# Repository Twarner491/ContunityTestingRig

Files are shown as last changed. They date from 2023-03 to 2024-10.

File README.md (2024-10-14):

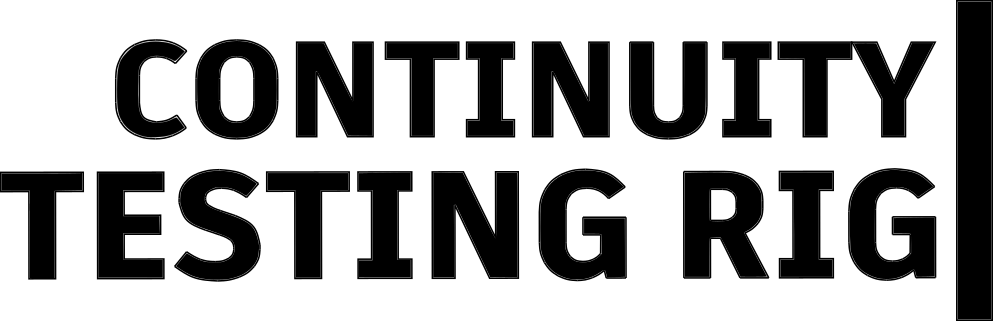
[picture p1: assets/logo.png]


### Devoloped by [Drew Griggs](http://fabacademy.org/2021/labs/charlotte/students/drew-griggs/about/) and [Teddy Warner](https://teddywarner.org/About-Me/about/).

## Documentation -

Our project idea, as discussed with RhythmLink, is a continuity testing rig. This project will be capable of testing and displaying the results of the pinout connections between two ends of a cable with different headers. Our goal is to create a continuity testing rig capable of testing and displaying the connections between the ends of two different cable headers. We will display the results to a webpage using the Raspberry Pico W microcontroller.

The concept behind this project is simple, but our method of display, as well as some methods to reduce the GPIO pins required for the microcontroller will be quite complex, so we worry that we might run into some issues here. The most challenging part of this project will likely be getting the web server to run correctly, as we will be using a RPI Pico W to host the server, but there are very few examples of a project such as this compared to something like an Arduino. A successful project would be able to test the continuity in real time and refresh the users web browser through a visually appealing display.

We used a few sources as guides to setting up a RPI web server, mainly Tom’s Hardware and the Raspberry Pi website - see the *sources* section below.

Our project is significantly more complex than these simple web servers, however, as we will refresh the page automatically, include some javascript and more complex HTML elements to improve the aesthetic, not to mention the continuity testing aspects.

Through the development of the project, we learned a great deal about the principles of static site design, multimedia design with 3D printing, and the integration of software and hardware components. As we developed the initial design stages of the project, we reminded ourselves of the horrors of debugging, going through countless coexisting issues that were causing the failure of our project. As we built up our initial prototype, we discovered, and ultimately resolved, issues involving our diode array, web server generation, board design, and many more. Similarly to our Fab Academy projects, we had many parts working in conjunction with each other. As we traversed the design and manufacturing process, we once again were reminded of the difficulty of getting each component of the project successfully integrated. At times, we would wonder from which component of the project our errors arose from.

Some of the major issues we encountered were due to errors in the board design. Due to an oversight in the main board, we did not include diodes for the final point of connection between each diode chain and output pin, which caused issues with reading pins that should not be high. Furthermore, we had an issue with our self test function. We initially decided to implement transistors to toggle and check each output and input pin, but due to voltage jumping between Gate and Drain despite no Source voltage, this part was unsuccessful. As such, we will not be making any further changes to the prototype, other than implementing a basic self test function with a predetermined cable.

### Electronic Design

The testing rig will likely consist of two separate boards, one main logic and interpretation board and one header board. The logic board will include a RPi Pico W to host the server and interpret data, a power regulation module, a diode array to reduce specific pins into their binary values (to conserve GPIO pins), and a large 2x20 pin header. The header board will include the connectors for each end of the cable and the 2x20 pin connector, as well as a possible self test function to ensure the functionality of the rig. The self test will include a jump between specific pins on each module, and an LED that will flash green assuming the test passes.

We used a few methods to allow the project to be operable on the Raspberry Pico. We designed and implemented an array of diodes to convert any individual input into a binary representation of its pin value, allowing us to test and read 15 possible different wires through 4 input pins. For the header connector board, we designed custom eagle footprints and libraries for the two types of connectors, as well as adding self-test circuits that will connect pins through the switch of a transistor.

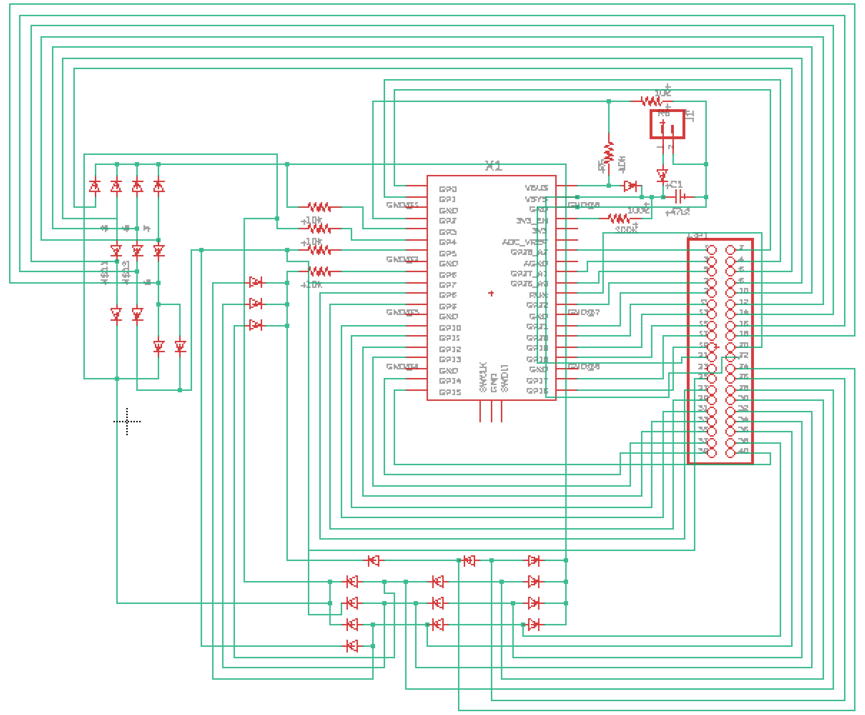
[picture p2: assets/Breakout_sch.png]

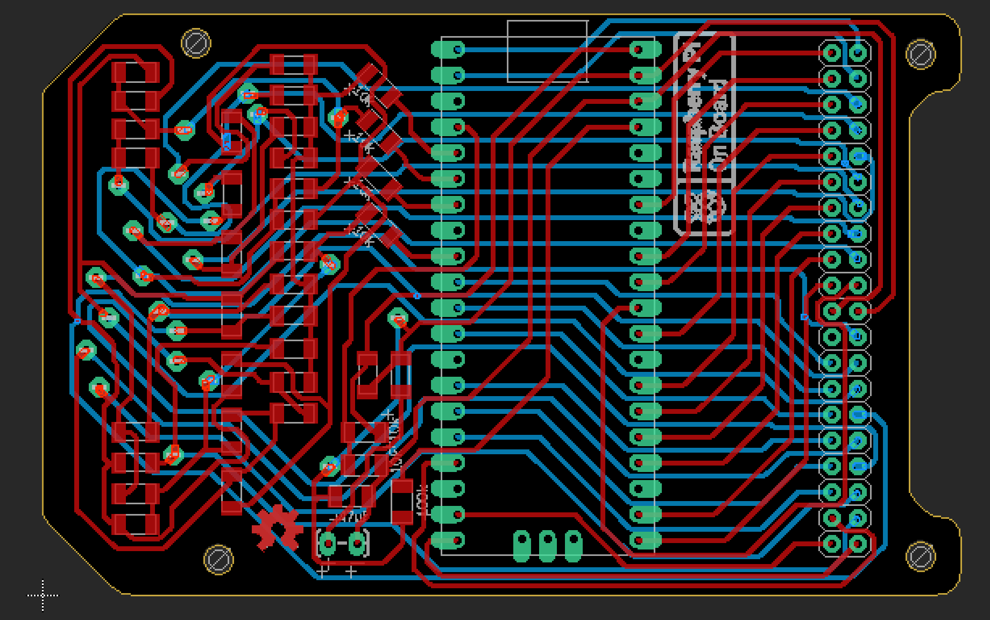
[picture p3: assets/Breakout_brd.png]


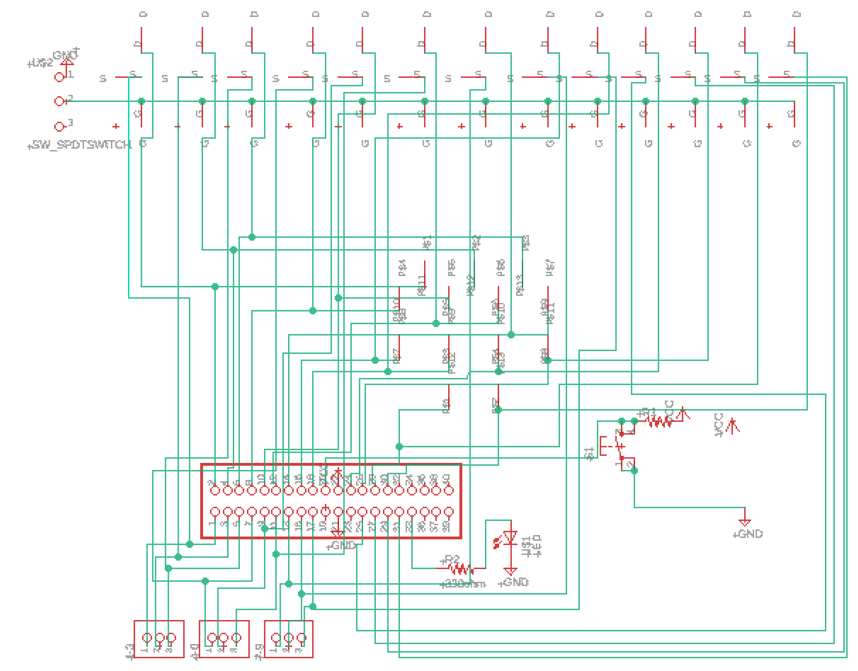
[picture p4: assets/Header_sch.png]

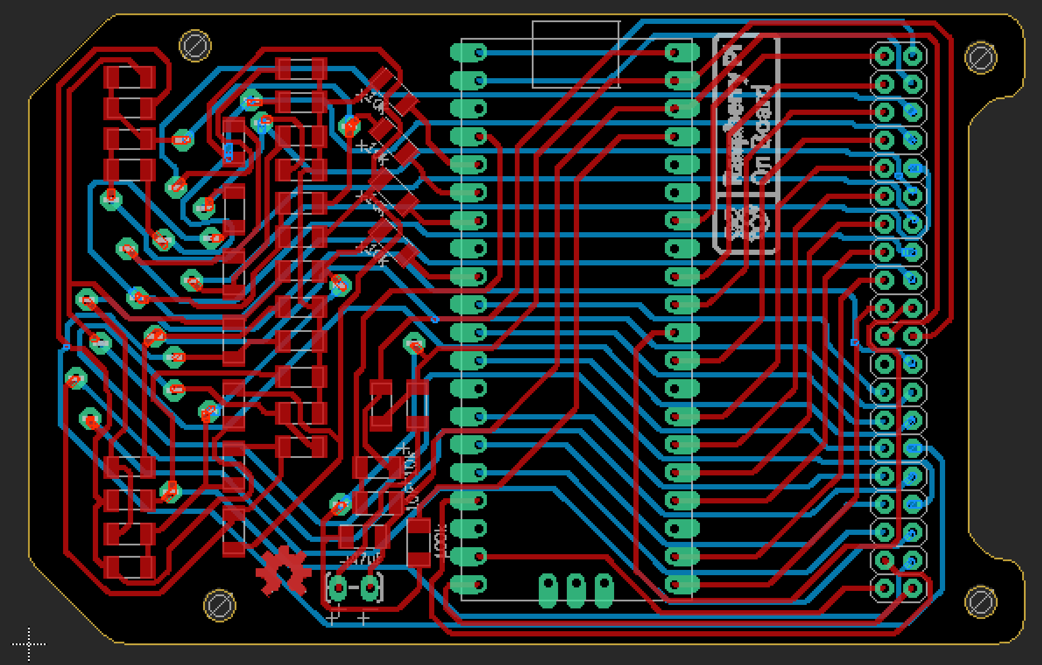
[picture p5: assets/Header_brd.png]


Our project went somewhat to plan. Due to some issues in the testing of our board due to the precision of our lab’s PCB mills as well as the complexity of our board, we had some issues testing the main board. We eventually fixed a bug in the diode array, and the main board was working. The header board took less time, as it was less complex, but due to some issues with voltages jumping across transistors despite no source voltage, we were unable to include our initially planned self test function. After discussions with Rhythmlink, however, we determined that this would not be an issue, and since the board worked without the transistors soldered, we continued with testing. Web and software design and testing took the majority of our allocated time, as this was the first project of this type for both of us, so it took some getting used to programming a web server through micropython.

We mostly used tools oriented to PCB design in our project. We spent the majority of our machine use on the Bantam PCB mills, with some 3D printing of our enclosure towards the end of our project. Our files were EagleCad .sch and .brd schematic and boards, python files, fusion project files, and html files.

### Software

The operation of the Pico makes designing and editing a webpage in real time very annoying. It requires a string object to be sent through a library in the Pico, so we had to code a way to implement the updates of the test through splicing strings together. Apart from some hiccups in the testing of this component, however, the code was fairly simple. It loops through each of nine output pins, and reads the corresponding binary value of the input pins that corresponds to the pin number in the header cable.

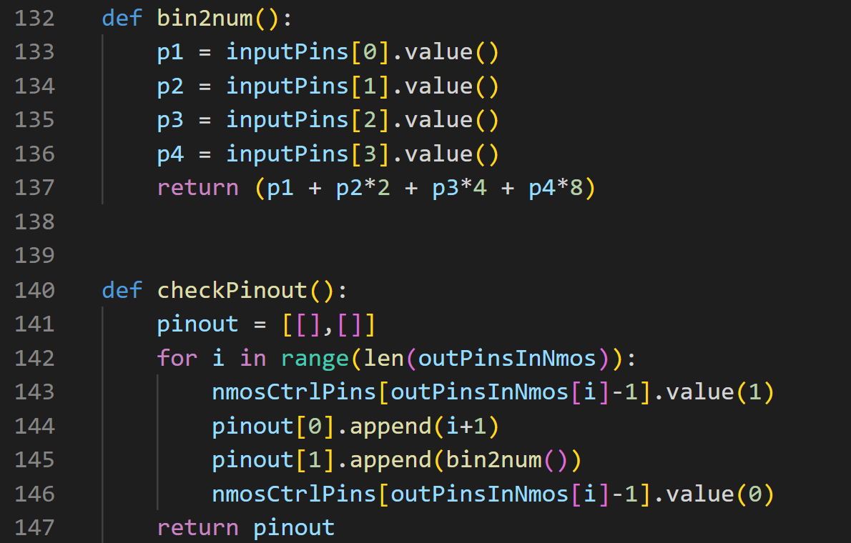
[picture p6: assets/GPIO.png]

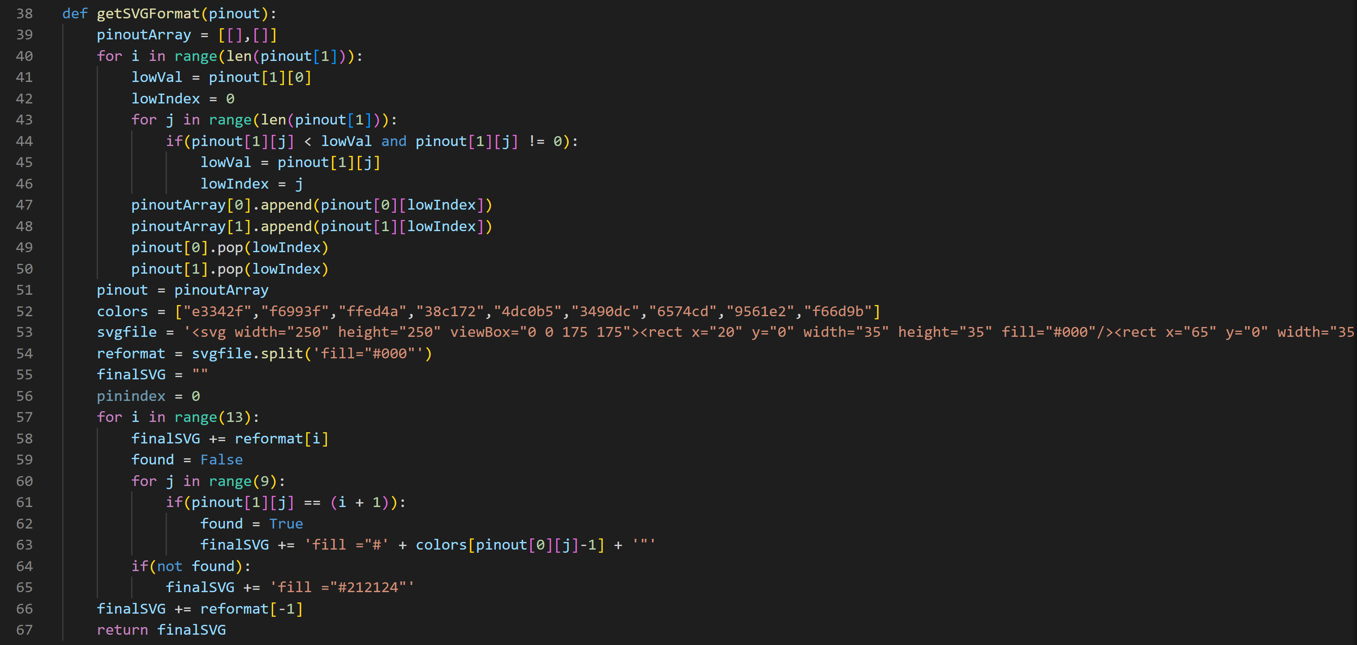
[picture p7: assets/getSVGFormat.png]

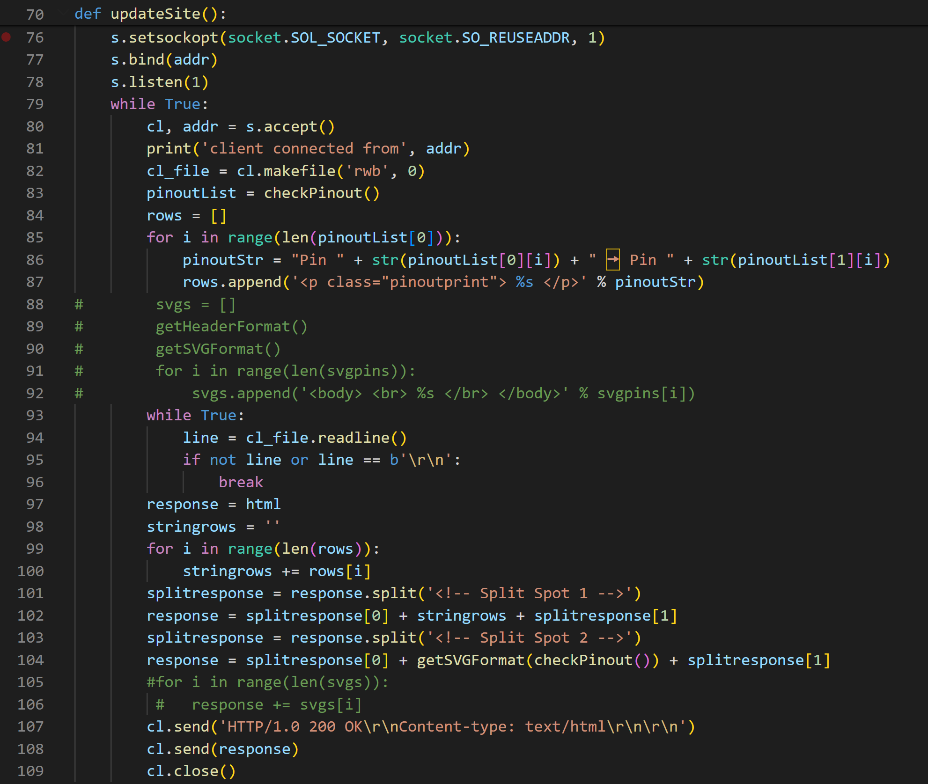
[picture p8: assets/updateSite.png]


### CAD

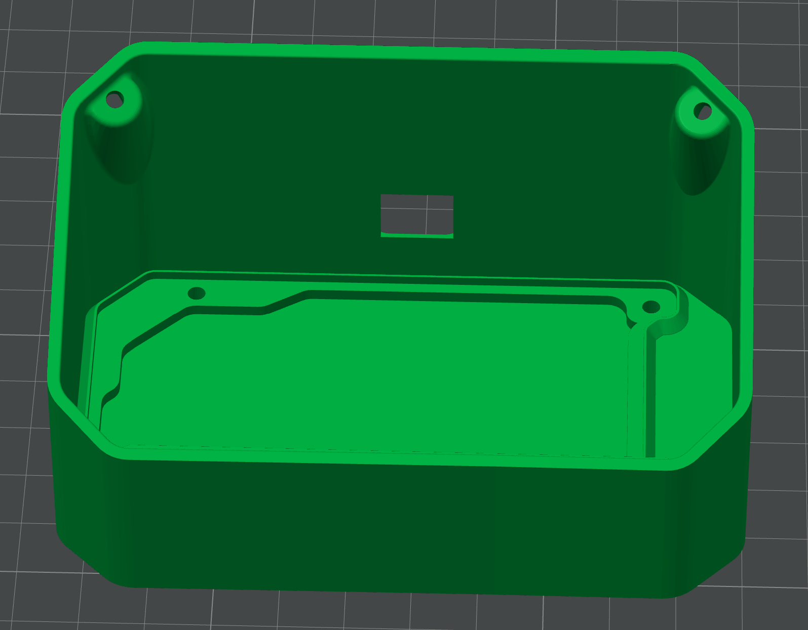
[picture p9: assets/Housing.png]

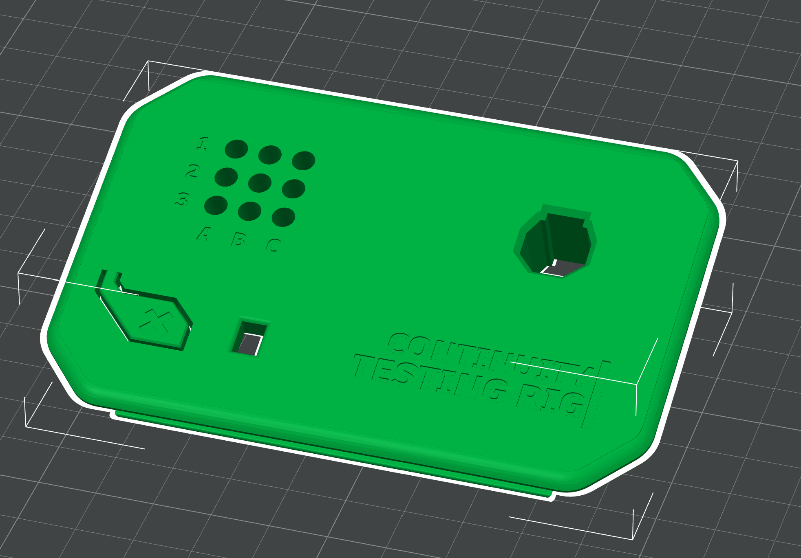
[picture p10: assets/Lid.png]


### Testing

https://github.com/user-attachments/assets/56f717f2-6f56-4a5b-b8bf-3c429beb7c11

https://github.com/user-attachments/assets/bd0a2b19-7a08-46a7-8804-3f2991451b49

### Assembly Instructions

- Download necessary files from github (link above)
- 3D print outer case
- Order or manufacture main and header board
- Solder components to each board
- Download Thonny and the python script
- Use dupont connectors and solid wires to create header cable adapters
- Add your wifi information to the ssid and password in the python file
- Boot the pico w with the boot file. Instructions can be found on raspberry pico article
- Run the script

## Sources -
 - [https://www.tomshardware.com/how-to/raspberry-pi-pico-setup](https://www.tomshardware.com/how-to/raspberry-pi-pico-setup)
 - [https://datasheets.raspberrypi.com/picow/pico-w-datasheet.pdf](https://datasheets.raspberrypi.com/picow/pico-w-datasheet.pdf)

---
- [Fork this repository](https://github.com/Twarner491/ContunityTestingRig/fork)
- [Watch this repo](https://github.com/Twarner491/ContunityTestingRig/subscription)
- [Create issue](https://github.com/Twarner491/ContunityTestingRig/issues/new)

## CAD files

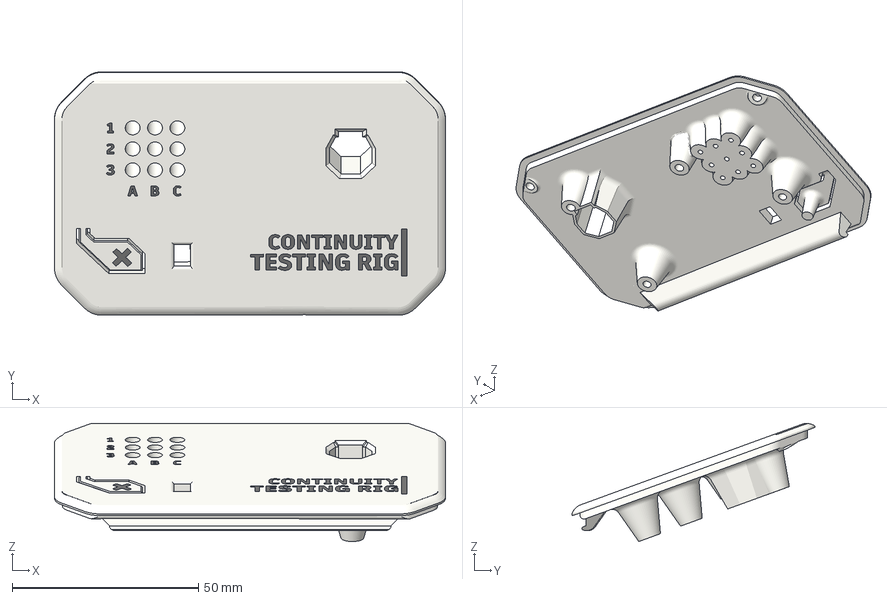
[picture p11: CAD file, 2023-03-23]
CAD/3DPrintedLid.3mf
104.9 x 65.3 x 31.7 mm

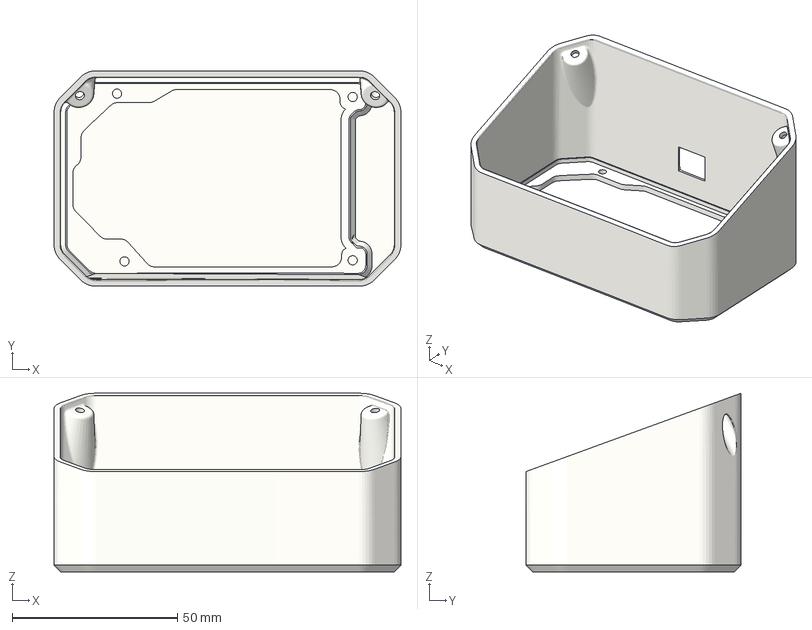
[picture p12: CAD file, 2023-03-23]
CAD/3dPrintedHousing.3mf
104.9 x 65.2 x 54.0 mm

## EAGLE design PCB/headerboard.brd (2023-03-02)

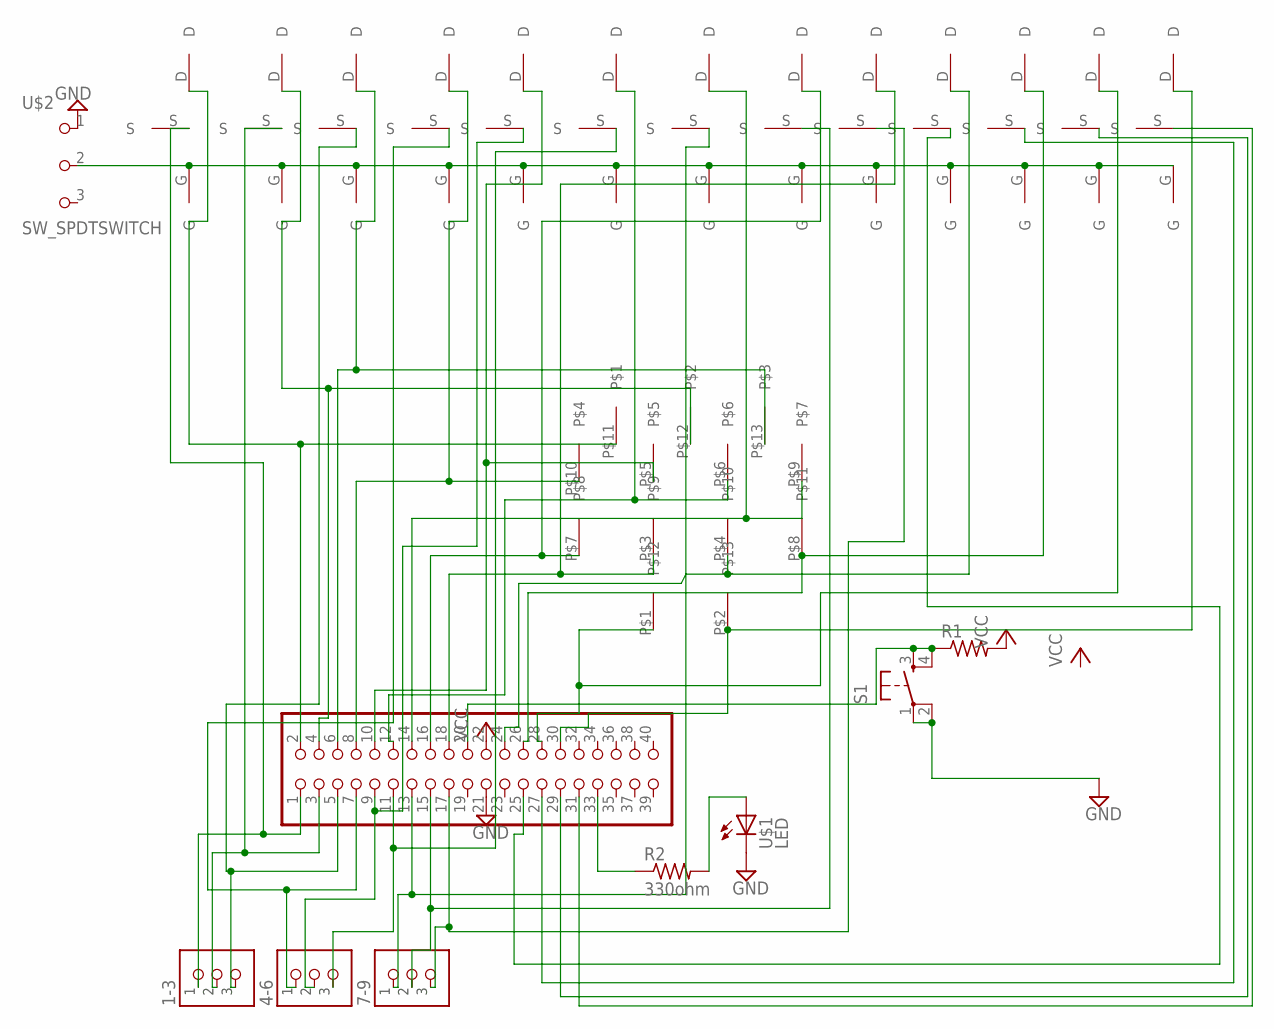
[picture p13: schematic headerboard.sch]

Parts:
1-3, 4-6, 7-9: CONN_03_TERM'-FABLAB'; ED555DS-3DS
JP1: PINHD-2X20; 2X20
R1: R1206FAB
R2: 330ohm; R1206FAB
S1: SW_SWITCH_TACTILE_6MM6MM_SWITCH; 6MM_SWITCH
U$1: LED; LED1206
U$2: SW_SPDTSWITCH; SPDTSWITCH
U$3, U$4, U$5, U$6, U$7, U$8, U$9, U$10, U$11, U$12, U$13, U$14, U$15: SOT23NMOS
U$19: 13PINHEADER; 13HEADER

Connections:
GND: JP1.21, S1.1, S1.2 (P1), U$1.2 (C), U$2.1
unnamed: U$2.2, U$3.G, U$4.G, U$5.G, U$6.G, U$7.G, U$8.G, U$9.G, U$10.G, U$11.G, U$12.G, U$13.G, U$14.G, U$15.G
unnamed: JP1.2, U$3.D, U$19.P$11
unnamed: JP1.4, U$4.D, U$19.P$12
unnamed: JP1.6, U$5.D, U$19.P$13
unnamed: JP1.8, U$6.D, U$19.P$10
unnamed: JP1.12, U$8.D, U$19.P$6
unnamed: JP1.26, U$13.D, U$19.P$8
unnamed: JP1.14, U$9.D, U$19.P$9
unnamed: JP1.16, U$10.D, U$19.P$7
unnamed: JP1.18, U$11.D, U$19.P$3
unnamed: 1-3.2, JP1.3, U$4.S
unnamed: JP1.28, U$14.D, U$19.P$1
unnamed: JP1.24, U$12.D, U$19.P$4
unnamed: JP1.30, U$15.D, U$19.P$2
unnamed: 1-3.3, JP1.5, U$5.S
unnamed: JP1.20, R1.1, S1.3 (S), S1.4 (S1)
unnamed: 4-6.1, JP1.7, U$6.S
unnamed: 4-6.2, JP1.9, U$7.S
unnamed: 4-6.3, JP1.11, U$8.S
unnamed: 7-9.1, JP1.13, U$9.S
unnamed: JP1.10, U$7.D, U$19.P$5
unnamed: 7-9.2, JP1.15, U$10.S
unnamed: 7-9.3, JP1.17, U$11.S
unnamed: JP1.25, U$12.S
unnamed: JP1.27, U$13.S
unnamed: JP1.29, U$14.S
unnamed: JP1.31, U$15.S
unnamed: JP1.33, R2.1
unnamed: R2.2, U$1.1 (A)
unnamed: 1-3.1, JP1.1, U$3.S
VCC: JP1.22, R1.2

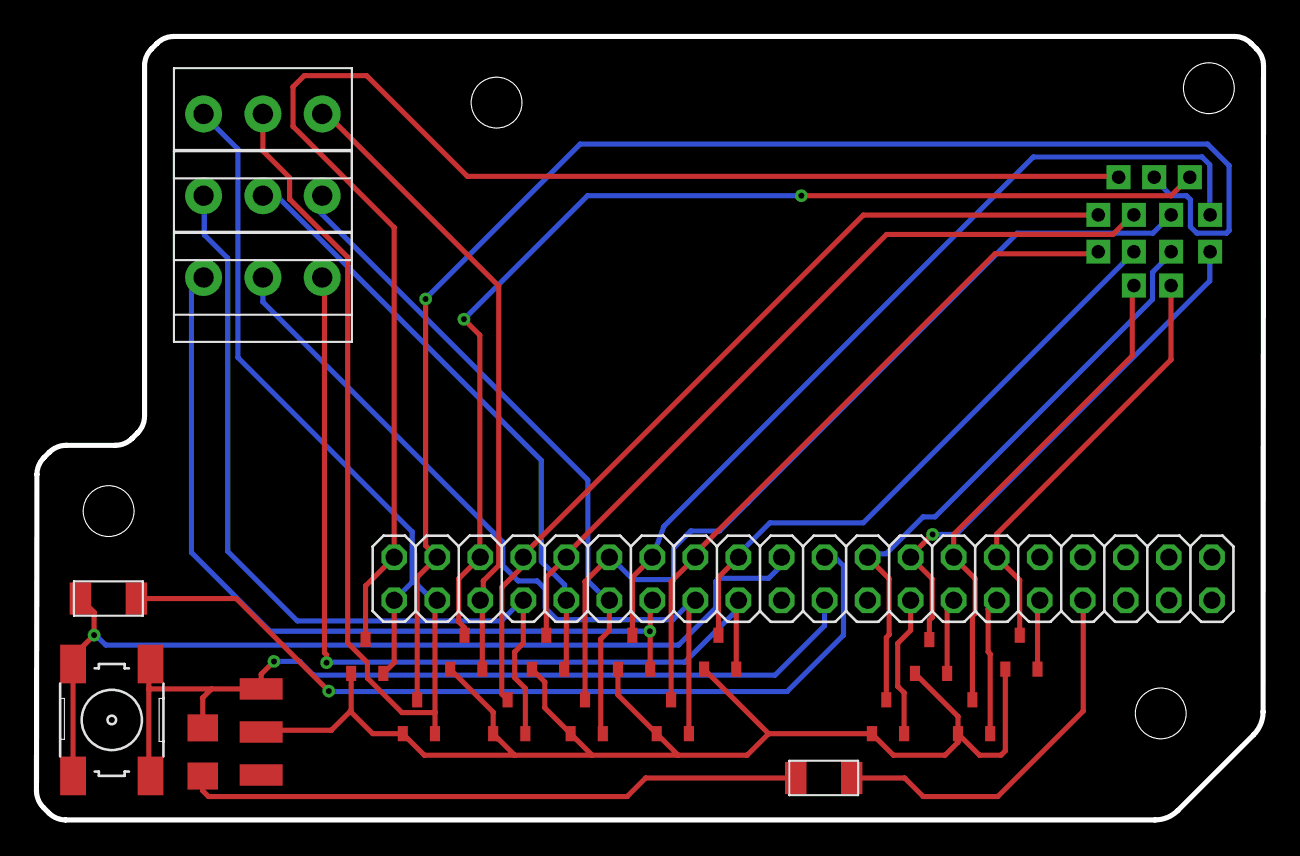
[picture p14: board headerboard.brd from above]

Board: 2 copper layers, 72.4 x 46.2 mm, 23 parts (0 on the bottom side), 32 nets.

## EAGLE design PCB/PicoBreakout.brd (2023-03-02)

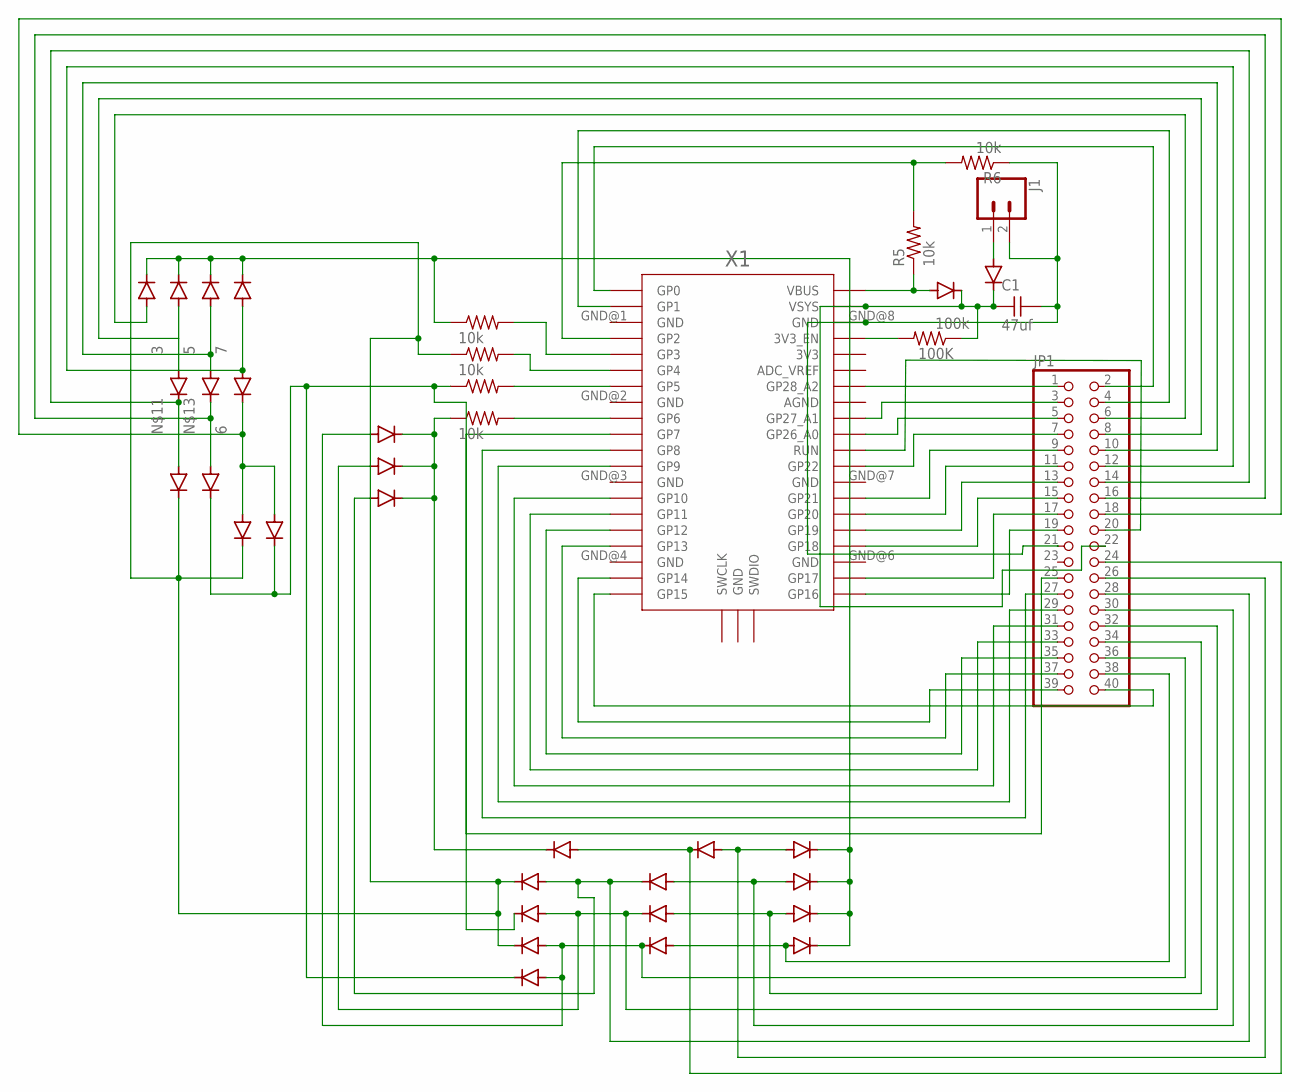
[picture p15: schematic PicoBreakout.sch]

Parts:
100K: 100k; R1206FAB
C1: 47uf; C1206FAB
D1, D2, D3, D4, D5, D6, D7, D8, D9, D10, D11, D12, D13, D14, D15, D16, D17, D18, D19, D20, D21, D22, D23, D24, D25, D26, D27, D28, D29: SCHOTTKY; MINI-SMA
J1: CONN_02LOCK_LONGPADS; 1X02_LOCK_LONGPADS
JP1: PINHD-2X20; 2X20
R1, R2, R3, R4, R5, R6: 10k; R1206FAB
X1: RPI_PICO_IG-TH; RPI_PICO_TH

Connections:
1: D1.KATHODE, D2.KATHODE, D3.KATHODE, D13.KATHODE, D14.KATHODE, D15.KATHODE, D16.KATHODE, D24.KATHODE, R1.1
3: D1.ANODE, D4.ANODE, JP1.8
4: D7.KATHODE, D17.KATHODE, D18.KATHODE, D25.KATHODE, R2.1
5: D2.ANODE, D5.ANODE, JP1.10
6: D6.KATHODE, D7.ANODE, D8.ANODE, JP1.18
7: D3.ANODE, D6.ANODE, JP1.12
8: D21.KATHODE, D22.KATHODE, D23.KATHODE, D26.KATHODE, R4.1
9: D9.ANODE, D13.ANODE, JP1.26
10: D10.KATHODE, D17.ANODE, D23.ANODE, JP1.28
11: D10.ANODE, D14.ANODE, JP1.30
12: D11.KATHODE, D19.ANODE, D22.ANODE, JP1.32
13: D11.ANODE, D15.ANODE, JP1.34
14: D12.KATHODE, D18.ANODE, D20.ANODE, D21.ANODE, JP1.36
15: D12.ANODE, D16.ANODE, JP1.38
unnamed: R1.2, X1.GP3
unnamed: R2.2, X1.GP4
unnamed: R3.2, X1.GP5
unnamed: R4.2, X1.GP6
unnamed: D8.KATHODE, D19.KATHODE, D20.KATHODE, D27.KATHODE, R3.1
unnamed: D24.ANODE, JP1.6
unnamed: D4.KATHODE, D25.ANODE, JP1.14
unnamed: D9.KATHODE, D26.ANODE, JP1.24
unnamed: D5.KATHODE, D27.ANODE, JP1.16
unnamed: D28.ANODE, J1.1
unnamed: C1.2, J1.2, JP1.21, R6.1, X1.GND@8 (GND)
unnamed: 100K.1, C1.1, D28.KATHODE, D29.KATHODE, JP1.22, X1.VSYS
unnamed: R5.2, R6.2, X1.GP2
unnamed: JP1.1, X1.GP28_A2
unnamed: 100K.2, X1.3V3_EN
unnamed: JP1.3, X1.GP27_A1
unnamed: JP1.5, X1.GP26_A0
unnamed: JP1.7, X1.GP22
unnamed: JP1.9, X1.GP21
unnamed: JP1.11, X1.GP20
unnamed: JP1.13, X1.GP19
unnamed: JP1.15, X1.GP18
unnamed: JP1.17, X1.GP17
unnamed: JP1.19, X1.GP16
unnamed: JP1.40, X1.GP15
unnamed: JP1.39, X1.GP14
unnamed: JP1.35, X1.GP12
unnamed: JP1.33, X1.GP11
unnamed: JP1.31, X1.GP10
unnamed: JP1.29, X1.GP9
unnamed: JP1.27, X1.GP8
unnamed: JP1.25, X1.GP7
unnamed: JP1.2, X1.GP0
unnamed: JP1.4, X1.GP1
unnamed: JP1.37, X1.GP13
unnamed: JP1.20, X1.RUN
unnamed: D29.ANODE, R5.1, X1.VBUS

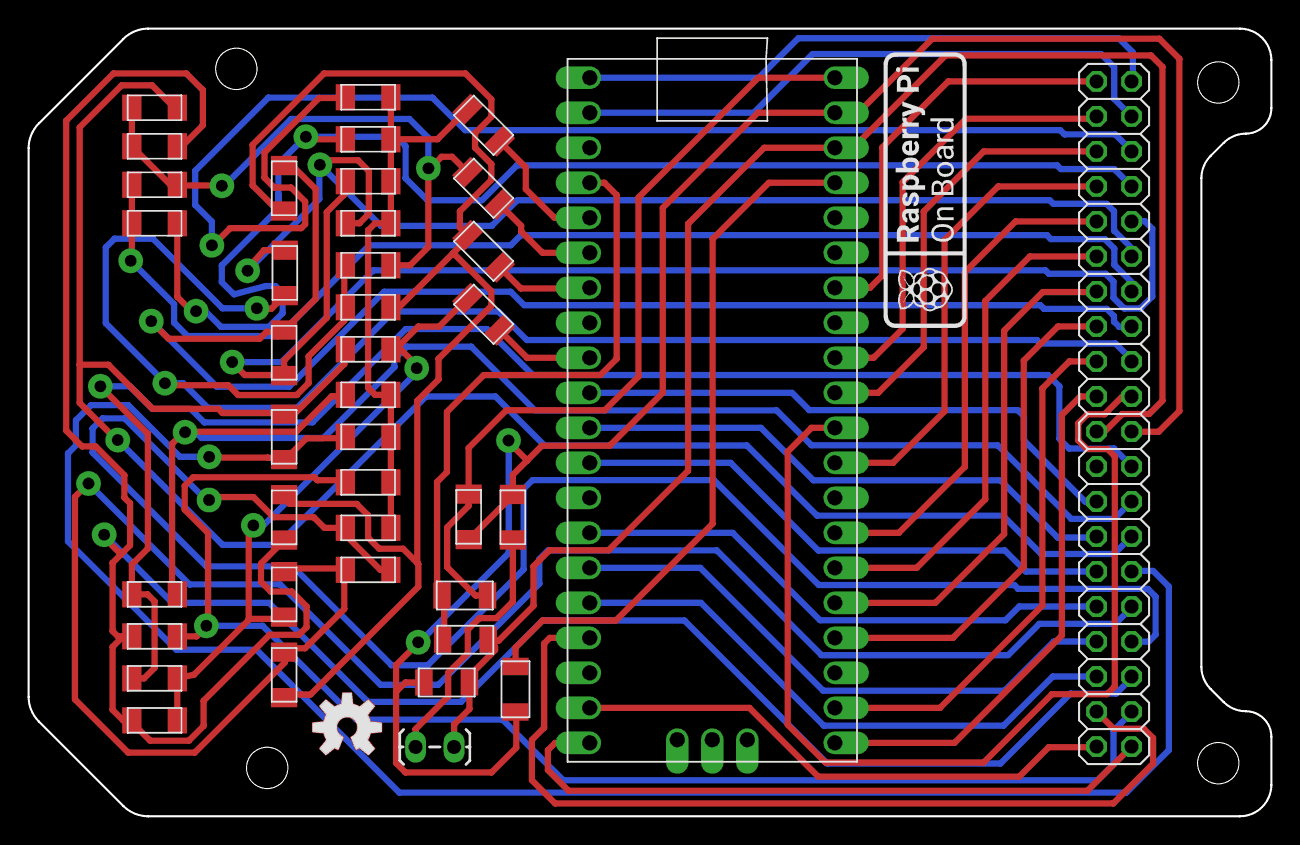
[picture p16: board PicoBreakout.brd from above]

Board: 2 copper layers, 90.2 x 57.1 mm, 43 parts (0 on the bottom side), 51 nets.

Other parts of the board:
U$2: OSHW-LOGO-M_COPPER
U$3: RASPI_ON_BOARD_LOGO_20MM
U$4: OSHW-LOGO-M

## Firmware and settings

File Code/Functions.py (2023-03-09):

#(c) Drew Griggs & Teddy Warner - (2023)

#This work may be reproduced, modified, distributed, performed, and displayed
#for any purpose, but must acknowledge Teddy Warner.
#Copyright is retained and must be preserved. The work is provided as is;
#no warranty is provided, and users accept all liability.

import sys
import rp2
from machine import Pin
import network
import socket
import utime

inputPins = []
outputPins = []



#main site function

def updateSite():   
    page = open("index.html","r")
    html = page.read()
    page.close()
    addr = socket.getaddrinfo('0.0.0.0', 80)[0][-1]
    s = socket.socket()
    s.setsockopt(socket.SOL_SOCKET, socket.SO_REUSEADDR, 1)
    s.bind(addr)
    s.listen()
    print("listening on", addr)
    while True:
        cl, addr = s.accept()
        print('client connected from', addr)
        cl_file = cl.makefile('rwb', 0)
        pinoutList = checkPinout(0)[1]
        rows = []
        for i in range(len(pinoutList[0])):
            pinoutStr = "Pin " + str(pinoutList[0][i]) + " --> Pin " + str(pinoutList[1][i])
            rows.append('<body> <br> %s </br> </body>' % pinoutStr)
        svgs = []
        getHeaderFormat()
        svgpins = getSVGFormat()
        if(svgpins == -2):
            svgs.append('<body><br>No SVG Format File Found</br></body>')
        else:
            for i in range(len(svgpins)):
                svgs.append('<body> <br> %s </br> </body>' % svgpins[i])
        while True:
            line = cl_file.readline()
            if not line or line == b'\r\n':
                break
    #    rows = '<body> %s </body>' % pinoutStr
        response = html
        for i in range(len(rows)):
            response += rows[i]
        for i in range(len(svgs)):
            response += svgs[i]
        cl.send('HTTP/1.0 200 OK\r\nContent-type: text/html\r\n\r\n')
        cl.send(response)
        cl.close()






#setup functions

def ntwkconnect(netssid, netpw):
    ssid = netssid
    password = netpw
    wlan = network.WLAN(network.STA_IF)
    wlan.active(True)
    wlan.connect(ssid, password)
    # Wait fo
    # r connect or fail
    max_wait = 15
    while max_wait > 0:
      if wlan.status() < 0 or wlan.status() >= 3:
        break
      max_wait -= 1
      print('waiting for connection...')
      utime.sleep(1)
    # Handle connection error
    if wlan.status() != 3:
        return -1
    else:
        print('connected')
        status = wlan.ifconfig()
        print( 'ip = ' + status[0])
        return [0,status[0]]

def setup(inPinNums,outPinNums): #pin setup
    #gpio pin numbers
    inPins = inPinNums
    outPins = outPinNums
    #create and fill arrays of pin objects, pinout array
    inputPins = []
    outputPins = []
    for i in range(len(inPins)):
        inputPins.append(Pin(inPins[i], Pin.IN)) #fill input pin object array with new pin object
    for i in range(len(outPins)):
        outputPins.append(Pin(outPins[i], Pin.OUT))
        outputPins[i].value(0) #default value
    return (inputPins, outputPins)






#Pin test functions

def checkPinout(GPIOpins):
    pinout = [[],[]]
    outputPins = GPIOpins[1][0] #weird way functions pass arguments
    inputPins = GPIOpins[0][0]
    for i in range(len(outputPins)):
        pinout[0].append(i+1) #start building pinout array
    r = "Pinout:"
    #String to return
    for i in range(len(outputPins)):
        try:
            outputPins[i].value(1) #set pin to high
        except:
            utime.sleep(0.01)
        utime.sleep(0.01)
        p1 = inputPins[0].value()
        p2 = inputPins[1].value()
        p3 = inputPins[2].value()
        p4 = inputPins[3].value() #read input pin value (high = 1, low = 0)
        try:
            outputPins[i].value(0) #reset pin to low
        except:
            utime.sleep(0.01)
        pin = bin2num(p1,p2,p3,p4)
        pinout[1].append(pin) #set pinout pin to binary equivalent of inputs
        r += "Pin " + str(i) + " --> Pin " + str(pin) + '\n' #build string equivalent to array (display purposes)
    return [r,pinout]



def bin2num(a, b, c, d):
    z = a
    z += b << 1
    z += c << 2
    z += d << 3
    #add the equivalent value of the bit
    return z
    #return the equivalent pin value




#formatting functions

def getHeaderFormat(headertype):
    colorformat = [[],[]]
    colors = []
    numPins = []
    with open("headerformat.txt", "r") as file: #basically a try catch loop
        headerlist = file.read() #read headerformat text file
        file.close()
        headerlist = headerlist.split('\n')
        match headertype:
            case "2":
                headerlist = headerlist[0]
            case "4":
                headerlist = headerlist[1]
            case "L":
                headerlist = headerlist[2]
            case _:
                print("no file go work or header type bad")
        headerlist = headerlist[2:]
        splitHeader = headerlist.split(' ') #split by space
        colors = splitHeader[1][1:(len(splitHeader[1])-1)].split(',') #colors list is set to the colors defined in the format file
        numPins = splitHeader[0][1:(len(splitHeader[0])-1)].split(',')
        numofpins = 0
        for i in range(len(numPins)):
            numofpins += int(numPins[i])
        if(int(len(colors))!= numofpins): #check if the format is correct, else ask to reformat
            print("Missing pin colors, add 'EMPTY' for a disconnected pin in the header")
            return -1 #incorrect header format error case
        return numPins, colors
    return -2 #no file error case

def getSVGFormat(colorcodes):
    svgcolors = colorcodes
    with open("13PinHeader.svg","r") as file:
        svgfile = file.read()
        file.close()
        reformat = svgfile.split('fill="#000000"')
        svgpins = ""
        while len(reformat) > 1:
            colorx = svgcolors.pop(0)
            if(colorx == "EMPTY"):
                colorx = "9BC"
            svgpins += reformat.pop(0) + 'fill="#' + colorx + '"'
        svgpins += reformat.pop()
        return svgpins
    return -2

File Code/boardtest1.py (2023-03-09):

#(c) Drew Griggs & Teddy Warner - (2023)

#This work may be reproduced, modified, distributed, performed, and displayed
#for any purpose, but must acknowledge Teddy Warner.
#Copyright is retained and must be preserved. The work is provided as is;
#no warranty is provided, and users accept all liability.

import machine
import rp2
from machine import Timer
from machine import Pin
import utime
import socket
import network


ssid = 'ATTdWyTMkI'
password = 'wwtqe#2dak6a'


inPinNums = [3,4,5,6]
inputPins = []

nmosCtrl = [7,8,9,10,17,18,19,20,21,22,26,27,28]
nmosCtrlPins = []

outPinsInNmos = [13,12,11,10,9,8,7,6,5] #index of nmos pins for 9 pin header

for i in range(len(inPinNums)):
    inputPins.append(Pin(inPinNums[i], Pin.IN, Pin.PULL_DOWN))

for i in range(len(nmosCtrl)):
    nmosCtrlPins.append(Pin(nmosCtrl[i], Pin.OUT))

ledPin = Pin(11,Pin.OUT)


def getSVGFormat(pinout):
    colors = ["01B","0D2","1FF","800","C80","CF0","E0F","652","326"]
    svgfile = '<svg width="170" height="170" viewBox="0 0 175 175"><rect x="20" y="0" width="35" height="35" fill="#000"/><rect x="65" y="0" width="35" height="35" fill="#000"/><rect x="110" y="0" width="35" height="35" fill="#000"/><rect x="0" y="45" width="35" height="35" fill="#000"/><rect x="45" y="45" width="35" height="35" fill="#000"/><rect x="90" y="45" width="35" height="35" fill="#000"/><rect x="135" y="45" width="35" height="35" fill="#000"/><rect x="0" y="90" width="35" height="35" fill="#000"/><rect x="45" y="90" width="35" height="35" fill="#000"/><rect x="90" y="90" width="35" height="35" fill="#000"/><rect x="135" y="90" width="35" height="35" fill="#000"/><rect x="45" y="135" width="35" height="35" fill="#000"/><rect x="90" y="135" width="35" height="35" fill="#000"/></svg>'
    reformat = svgfile.split('fill="#000"')
    finalSVG = ""
    colorindex = 0
    for i in range(len(reformat)-1):
        finalSVG += reformat[i]
        if(pinout[1][i] == 0):
            finalSVG += 'fill="#000"'
        else:
            finalSVG += 'fill ="#' + colors[colorindex] + '"'
            colorindex += 1
    finalSVG += reformat[-1]
    return finalSVG


def updateSite():   
    page = open("index.html","r")
    html = page.read()
    page.close()
    addr = socket.getaddrinfo('0.0.0.0', 80)[0][-1]
    s = socket.socket()
    s.setsockopt(socket.SOL_SOCKET, socket.SO_REUSEADDR, 1)
    s.bind(addr)
    s.listen(1)
    while True:
        cl, addr = s.accept()
        print('client connected from', addr)
        cl_file = cl.makefile('rwb', 0)
        pinoutList = checkPinout()
        rows = []
        for i in range(len(pinoutList[0])):
            pinoutStr = "Pin " + str(pinoutList[0][i]) + " 🠚 Pin " + str(pinoutList[1][i])
            rows.append('<p class="pinoutprint"> %s </p>' % pinoutStr)
#        svgs = []
#        getHeaderFormat()
#        getSVGFormat()
#        for i in range(len(svgpins)):
#            svgs.append('<body> <br> %s </br> </body>' % svgpins[i])
        while True:
            line = cl_file.readline()
            if not line or line == b'\r\n':
                break
        response = html
        stringrows = ''
        for i in range(len(rows)):
            stringrows += rows[i]
        splitresponse = response.split('<!-- Split Spot 1 -->')
        response = splitresponse[0] + stringrows + splitresponse[1]
   #     splitresponse = response.split('<!-- Split Spot 2 -->')
    #    response = splitresponse[0] + getSVGFormat(checkPinout()) + splitrepsonse[1]
        #for i in range(len(svgs)):
         #   response += svgs[i]
        cl.send('HTTP/1.0 200 OK\r\nContent-type: text/html\r\n\r\n')
        cl.send(response)
        cl.close()

def networkConnect():
    wlan = network.WLAN(network.STA_IF)
    wlan.active(True)
    wlan.connect(ssid, password)
    # Wait for connect or fail
    max_wait = 15
    while max_wait > 0:
      if wlan.status() < 0 or wlan.status() >= 3:
        break
      max_wait -= 1
      print('waiting for connection...')
      utime.sleep(1)
    # Handle connection error
    if wlan.status() != 3:
       raise RuntimeError('network connection failed')
    else:
      print('connected')
      status = wlan.ifconfig()
      print( 'ip = ' + status[0] )


def bin2num():
    p1 = inputPins[0].value()
    p2 = inputPins[1].value()
    p3 = inputPins[2].value()
    p4 = inputPins[3].value()
    return (p1 + p2*2 + p3*4 + p4*8)


def checkPinout():
    pinout = [[],[]]
    for i in range(len(outPinsInNmos)):
        nmosCtrlPins[outPinsInNmos[i]-1].value(1)
        pinout[0].append(i+1)
        pinout[1].append(bin2num())
        nmosCtrlPins[outPinsInNmos[i]-1].value(0)
    return pinout
           
networkConnect()
updateSite()

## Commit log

2022-10-08 inital push
    [ContunityTestingRig.brd, ContunityTestingRig.sch]
2022-10-21 Trace Fix
    [PicoBreakout.brd]
2022-11-29 Advanced topics in engineering
    13 Pin header svg object to be displayed in website
2022-12-07 schematic push
    [PicoBreakout.brd, PicoBreakout.sch]
2023-01-05 PCB Updates
    [PicoBreakout.brd, PicoBreakout.sch]
2023-01-09 PCB v2
    [PicoBreakout.brd]
2023-01-10 PCB push
    [PicoBreakout.brd]
2023-01-31 updated run trace
    [PicoBreakout.brd, PicoBreakout.sch]
2023-01-31 added header board schematic
    [headerboard.sch]
2023-02-09 updated pico board
    [PicoBreakout.brd, PicoBreakout.sch]
2023-02-13 header board and schematic
    [headerboard.brd, headerboard.sch]
2023-02-15 brd updates
    [PicoBreakout.brd, PicoBreakout.sch]
2023-03-23 3MF Updates
    [3DPrintedLid.3mf, 3dPrintedHousing.3mf]

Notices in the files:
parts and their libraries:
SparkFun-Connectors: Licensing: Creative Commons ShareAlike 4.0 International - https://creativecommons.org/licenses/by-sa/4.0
